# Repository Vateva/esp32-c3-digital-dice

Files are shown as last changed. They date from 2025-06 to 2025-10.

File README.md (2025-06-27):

# ESP32-C3 Digital Dice

Simple digital dice using ESP32-C3 Super Mini with 1.3" OLED display and momentary button.

Main objective is to learn more about git/github and microcontrollers/C.

## Hardware Components

- ESP32 C3 Super Mini
- 1.3" Display (SH1106)
- Momentary Push Button
- LSM6DS3 Accelerometer
- Small 500mAh pouch LiPo
- TP4057 1A Charging module
- Small switch
- Dupont wires

## Test Wiring

The idea was to print a cubical casing and power the whole setup with a button cell, probably CR2477 as we will probably have vertical space to spare, but first we will build a working prototype powered by the USB-C port.

### Soldered pins to ESP32 C3 Super Mini

<div align="center">
    
</div>

### Common ground wire

<div align="center">
    
</div>

### Button wiring

<div align="center">
    
</div>

### Prototype for testing

<div align="center">
    
</div>

Now we use `testhardware.cpp` to test the setup.

<div align="center">
    
</div>

**Everything works!**

## Final Product

I ended up adding a few QoL upgrades to the initial idea/prototype:

- A small switch to turn power off completely between sessions
- A rechargeable 500mAh LiPo pouch, rechargeable through USB-C with a small TP4057 1A
- A LSM6DS3 accelerometer to add shake-to-roll capabilities

For the casing I decided to learn very basic Blender and designed and printed it myself with an Ender 3 Pro I got from a friend. The STL file will be in the repository in case someone wants to replicate the whole project.

### Wired Components (before casing)

Final product looks like this with everything wired but not placed inside the casing:

<div align="center">
    
</div>

<div align="center">
    
</div>

### Assembly Process

I glued the TP4057 1A on top of the pouch and glued it to the bottom of the casing. I also glued the ESP32-C3 to the side of the casing and added a small hydrogel film on top of the screen before placing it in the casing for extra protection.

### Final Product (in casing)

<div align="center">
    
</div>

<div align="center">
    
</div>

<div align="center">
    
</div>

## Demonstration Videos

Here are a couple of videos showcasing the dice rolling and the menu:

### Dice Roll 

[dice roll](https://github.com/user-attachments/assets/2823d9ca-534b-4626-b369-a73eaf9733b9)
### Menu

[menu](https://github.com/user-attachments/assets/94b1bece-dcf2-499f-b2bd-8fa810c06be8)

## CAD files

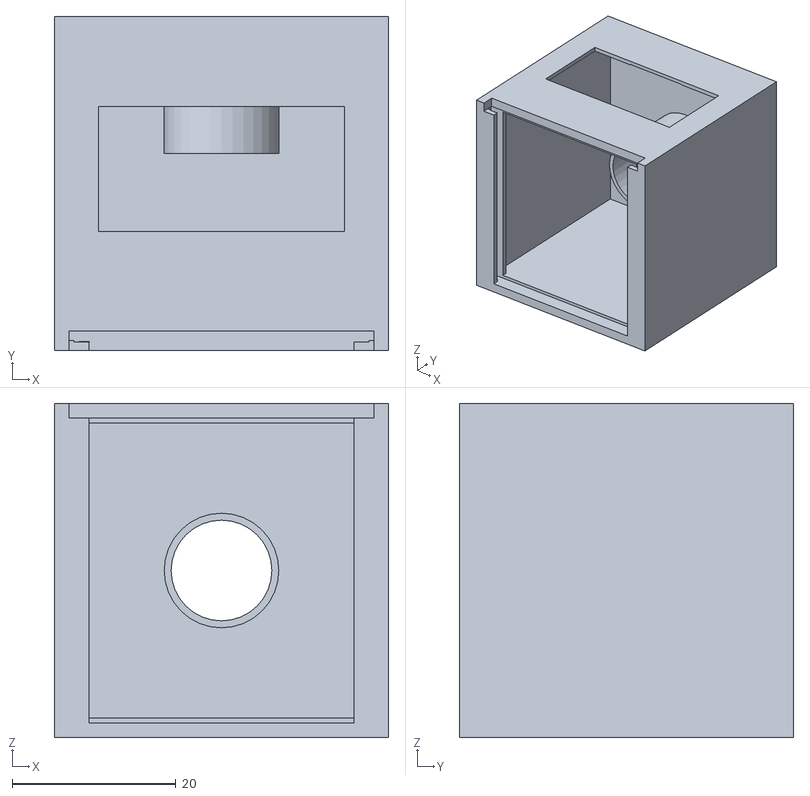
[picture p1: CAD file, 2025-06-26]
physical-casing-files/cubedice-applied modifiers-joined.stl
40.8 x 40.8 x 40.8

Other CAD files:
physical-casing-files/cubedice-no-battery-separator.blend

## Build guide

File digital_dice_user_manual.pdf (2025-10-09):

# DIGITAL DICE

# User Manual

⚄ ⚁ ⚅

# Contents

Quick Start Guide | 3
Button Controls | 3
Menu System | 4
Dice Configuration | 4
Roll History | 5
Configuration Settings | 5
Technical Specifications | 6

# Quick Start Guide

### Rolling Dice

Method 1: Button Press

1. Short press the button to roll your configured dice
2. Watch the animated roll
3. Results stay on screen for your configured duration

Method 2: Shake to Roll

(When accelerometer is enabled)

1. Simply shake the device
2. Dice will automatically roll with animation
3. Results display automatically

Quick Tip: The shake-to-roll feature is perfect for quick games and adds a tactile element to your digital dice experience!

### Entering the Menu

Long press the button (hold for approximately 2 seconds)

Release when menu appears on screen

# Button Controls

Action | Function
Short Press | Roll dice / Navigate menu options
Long Press (2 sec) | Enter menu / Select menu option

# Menu System

### Main Menu

Navigate through options with short presses. Long press to select.

Menu Option | Description
Dice | Configure which dice to roll
Roll History | View your last 6 rolls
Configuration | Adjust device settings
Exit | Return to standby mode

# Dice Configuration

Configure any combination of dice up to 8 total dice.

### Available Dice Types

Die Type | Sides | Description
Coin | 2 | Heads/Tails
D4 | 4 | 4-sided die
D6 | 6 | 6-sided die
D8 | 8 | 8-sided die
D10 | 10 | 10-sided die
D12 | 12 | 12-sided die
D20 | 20 | 20-sided die

### How to Configure

1. Enter Main Menu → Select "Dice"
2. Navigate to desired dice type
3. Long press to cycle through counts (0-8)
4. System enforces 8 dice maximum total
5. Select "Back" when finished

Example: You can configure 2×D6 + 1×D20 + 1×D4 = 4 dice total

# Roll History

View your last 6 rolls in chronological order:

Last: Most recent roll

n-2, n-3, etc.: Previous rolls

Note: Results are displayed in order from smallest to largest dice type: Coin → D4 → D6 → D8 → D10 → D12 → D20

# Configuration Settings

### Brightness

Options: 25%, 50%, 75%, 100%

Adjusts display contrast for different lighting conditions.

### Time to Clear

Range: 1.0 - 5.0 seconds (in 0.5s increments)

How long dice results remain on screen before auto-sleep. Useful for giving players time to record results.

Recommended: Use 2-3 seconds for fast-paced games, 4-5 seconds when players need to write down results.

### Stagger Time

Range: 0 - 5 frames

Animation delay between multiple dice. Higher values create a more dramatic sequential rolling effect.

0: All dice animate simultaneously

1-2: Slight delay, subtle effect

3-5: Pronounced sequential animation

### Accelerometer

Options: On / Off

On: Shake device to roll dice

Off: Button-only operation (saves power)

Power Saving: Disabling the accelerometer extends battery life during extended gaming sessions.

# Technical Specifications

### Hardware Components

Display | 128×64 OLED (SH1106 controller), I2C interface @ 0x3C
Processor | ESP32-C3 @ 80MHz (reduced from default 160MHz for power efficiency)
Accelerometer | LSM6DS3 6-axis IMU (I2C @ 0x6B)
Interface | Single button (active-low with pull-up) + motion sensing

### Functional Capabilities

Maximum Dice | 8 simultaneous dice
Roll History | Last 6 rolls retained in flash memory
Configuration Storage | All settings automatically saved to non-volatile memory

# DIGITAL DICE

Perfect for tabletop games,

### decision making, and any time

you need a fair random roll.

Key Features:

✓ All settings automatically saved ✓ Roll history preserved
✓ Low-power deep sleep mode ✓ Shake-to-roll capability
✓ Up to 8 dice simultaneously
For entertainment purposes only | Version 1.0

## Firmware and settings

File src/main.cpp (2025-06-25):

#include "config.h"
#include "lsm6ds3_acce.h"
#include "menu.h"
#include "rollDice.h"
#include "utils.h"
#include "welcome_bitmap.h"
#include <Adafruit_GFX.h>
#include <Adafruit_SH1106.h>
#include <Wire.h>
#include <driver/gpio.h>
#include <esp_sleep.h>

Adafruit_SH1106 display(-1);

// timing variables for sleep and debounce

unsigned long lastButtonPress = 0;
bool buttonPressed = false;

// function prototypes
void showWelcomeMessage();
void goToDeepSleep();
void handleWakeFromButton();

void setup() {

  gpio_hold_dis((gpio_num_t)DISPLAY_POWER_PIN); // disable hold on GPIO 4
  gpio_deep_sleep_hold_dis(); // disable deep sleep hold function


  // lower CPU frequency
  setCpuFrequencyMhz(80);

  // configure display pin
  pinMode(DISPLAY_POWER_PIN, OUTPUT);
  // turn display on
  digitalWrite(DISPLAY_POWER_PIN, HIGH);
  delay(50);

  // configure button with pullup resistor enabled
  pinMode(BUTTON_PIN, INPUT_PULLUP);

  // seeds random number generator
  randomSeed(esp_random());
  // loads configuration from flash memory
  loadConfiguration();

  // configure gpio wakeup for esp32-c3 deep sleep mode
  uint64_t wakeup_pin_mask = getAccelerometer() == 1 ? (1ULL << BUTTON_PIN) | (1ULL << ACCE_INT_PIN) : (1ULL << BUTTON_PIN);
  esp_deep_sleep_enable_gpio_wakeup(wakeup_pin_mask, ESP_GPIO_WAKEUP_GPIO_LOW);

  // initializes cleared display
  Wire.begin(SDA_PIN, SCL_PIN);

  nonGlitchyDisplayClear();
  display.begin(SH1106_SWITCHCAPVCC, 0x3C);

  // initializes acce
  bool motionSensorAvailable = initLSM6DS3();

  // check wake up reason
  esp_sleep_wakeup_cause_t wakeup_reason = esp_sleep_get_wakeup_cause();
  // set saved brightness
  setDisplayBrightness(getBrightness());

  // checks what caused the esp32 to wake up
  if (wakeup_reason == ESP_SLEEP_WAKEUP_GPIO) {

    handleWakeFromButton();

    goToDeepSleep();

  } else if (wakeup_reason == ESP_SLEEP_WAKEUP_TIMER) {

    // clear the screen
    nonGlitchyDisplayClear();
    // turns it off completely, controller included
    digitalWrite(DISPLAY_POWER_PIN, LOW);
    // and holds the pin low via RTC
    gpio_hold_en((gpio_num_t)DISPLAY_POWER_PIN);
    gpio_deep_sleep_hold_en();
    goToDeepSleep();

  } else {

    showWelcomeMessage();
    delay(1500);
    nonGlitchyDisplayClear();
    // turns it off completely, controller included
    digitalWrite(DISPLAY_POWER_PIN, LOW);
    // and holds the pin low via RTC
    gpio_hold_en((gpio_num_t)DISPLAY_POWER_PIN);
    gpio_deep_sleep_hold_en();
    goToDeepSleep();
  }
}

void loop() {}

void showWelcomeMessage() {

  int frameDelay = 200;
  int frame = 0;
  unsigned long startTime = millis();

  while (millis() - startTime < 4000) { // animate for 3 seconds
    display.clearDisplay();
    display.drawBitmap(0, 4, greyhound_allArray[frame], 128, 40, WHITE);
    display.drawBitmap(0, 44, welcome_image_dice_allArray[0], 128, 16, WHITE);
    display.display();
    delay(frameDelay);

    frame = (frame + 1) % 3; // cycles frames
  }
}

void goToDeepSleep() {

  // enters deep sleep mode - usb disconnects here
  esp_deep_sleep_start();
}

void handleWakeFromButton() {
  unsigned long buttonHoldStart = millis();
  bool longPressHandled = false;

  if (digitalRead(BUTTON_PIN) == HIGH && getAccelerometer() == 1) {
    // disable accelerometer interrupt during dice rolling
    gpio_intr_disable((gpio_num_t)ACCE_INT_PIN);

    rollDice();

    // Re-enable
    gpio_intr_enable((gpio_num_t)ACCE_INT_PIN);
    
    esp_sleep_enable_timer_wakeup(getTimeToClearDisplay() * 1000);
    gpio_hold_en((gpio_num_t)DISPLAY_POWER_PIN);
    gpio_deep_sleep_hold_en();
    return;
  }

  // Check hold duration while button is still pressed
  while (digitalRead(BUTTON_PIN) == LOW) {
    unsigned long holdDuration = millis() - buttonHoldStart;

    // Open menu immediately when threshold reached
    if (holdDuration >= LONG_PRESS_MS_ENTER_MENU && !longPressHandled) {
      openMenu();
      longPressHandled = true;
      // clear display when exiting menu
      nonGlitchyDisplayClear();
      // turns it off completely, controller included
      digitalWrite(DISPLAY_POWER_PIN, LOW);
      // and holds the pin low via RTC
      gpio_hold_en((gpio_num_t)DISPLAY_POWER_PIN);
      gpio_deep_sleep_hold_en();
      goToDeepSleep();
    }
  }

  // If button was released before long press threshold
  if (!longPressHandled) {
    // enables timer only when dice has been rolled
    esp_sleep_enable_timer_wakeup(getTimeToClearDisplay() * 1000);

    rollDice();
    gpio_hold_en((gpio_num_t)DISPLAY_POWER_PIN); // enable hold on GPIO 4
    gpio_deep_sleep_hold_en(); // enable hold function during deep sleep
    goToDeepSleep();
  }
}

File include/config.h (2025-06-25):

//configuration header file

//pins
#define SDA_PIN 5
#define SCL_PIN 6
#define BUTTON_PIN 4
#define ACCE_INT_PIN 2
#define DISPLAY_POWER_PIN 3

//button timing
#define DEBOUNCE_DELAY_MS 100
#define LONG_PRESS_MS_ENTER_MENU 500
#define LONG_PRESS_MENU_SELECTION 300

//menu state tracking
#define MENU_MAIN 0
#define MENU_HISTORY 1
#define MENU_DICE 2
#define MENU_CONFIG 3

//menu options count and current selection
#define MAIN_MENU_ITEMS 4
#define DICE_MENU_ITEMS 8
#define CONFIG_MENU_ITEMS 5

//default configuration values
#define BRIGHTNESS_DEFAULT 128
#define TIME_TO_CLEAR_DISPLAY_DEFAULT 3500
#define STAGGER_DEFAULT 2
#define ACCELEROMETER_DEFAULT 1
#define COIN_COUNT_DEFAULT 0
#define D4_COUNT_DEFAULT 0
#define D6_COUNT_DEFAULT 1
#define D8_COUNT_DEFAULT 0
#define D10_COUNT_DEFAULT 0
#define D12_COUNT_DEFAULT 0
#define D20_COUNT_DEFAULT 0

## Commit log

2025-06-06 improved deep sleep/screen clearing logic, bigger power savings
2025-06-09 implemented non glitchy/flashy display clearing via I2C, turning off of display for more battery preservation, implemented configuration saving, dice now dont have to be all the same, you can pick an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
2025-06-09 fixed constant wakinup every (getClearDisplayTime()*1000 seconds) by enabling the timer only if dice hs been rolled
    [main.cpp]
2025-06-13 changed dispaly to be connected to spio 4 instead of 3.3v to be able to turn the controller off too and save battery, fixed some headers and declarations ,fixed some comments
    [config.h, main.cpp]
2025-06-14 implemented RTC memoery for variables as to avoid flash read/write every dice roll, added flag to save in memoeryh only if something changed(dice or config), simplified dice selection logic in menu u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
    [config.h, main.cpp]
2025-06-14 fixed bug where saved brightness would not apply on wake up, create utils file to be tidy with functions, shifted the menu a few pixels visually, fixed a bug where time to clear fractional values wer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
    [main.cpp, utils.cpp]
2025-06-17 added shake to roll dice funcionality with a BMI160, i will probably replace it with a lsm6ds3 in the very near future
    [bmi160_acce.cpp, main.cpp]
2025-06-25 swapped accelerometer for an LSM6DS3, way less power hungry. Also added a small TP4057 1A to charge the 500mah pouch LiPo. Removed FPS option from menu and replaced it for an option to activate/deact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
    [config.h, lsm6ds3_acce.cpp, main.cpp]
2025-06-26 physical-casing-files/
    Added both stl and blender files in case someone wants to change something to the casing design.
    [cubedice-applied modifiers-joined.stl, cubedice-no-battery-separator.blend]
2025-06-26 Create placeholder
    Added both blender and stl files in case someone wants to change something of the casing design
